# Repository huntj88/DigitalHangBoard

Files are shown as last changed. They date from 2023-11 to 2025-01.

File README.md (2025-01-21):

# Digital Hangboard
#### Project Album and YouTube demo
* https://photos.app.goo.gl/wRxz9BxxeJGzHZhK6
* https://youtube.com/shorts/t4RoINdm0Y4

---

assembled hangboard
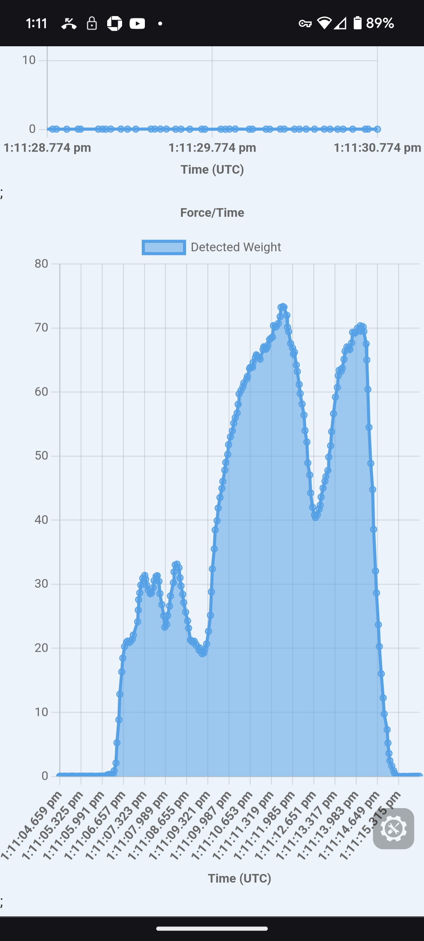
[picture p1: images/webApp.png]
web app


I thought it would be fun to create a Hangboard capable of measuring and logging how much weight I could apply through my fingertips. A hangboard is a tool that is commonly used by rock climbers, but usually they don't have integrated electronics.

Over the course of this project I was able to enjoy playing with (to varying degrees) 3d modeling, 3d printing, cnc routing, react + next.js, bluetooth, electrical engineering, firmware development.

I used an esp32 microcontroller to read the sensors and report the data to a tiny screen, as well as a web app over bluetooth.

To detect the weight I used 4 load cells and 4 high resolution analog to digital converters.
* https://www.adafruit.com/product/4538
* https://www.robotshop.com//products/micro-load-cell-50-kg

When I started this project I did not have access to a CNC router, but I did have a 3d printer. I designed the model so that it could be manufactured on either, which made it easy to iterate and validate my design with the tools at my disposal.

comparing 3d printed vs cnc routered parts
cnc router during routing operation

To make this work I designed the hangboard as a series of layers that was held together by Stainless Steel threaded rods, lock nuts, and washers.

* M5 x 150mm Fully Threaded Rod 304 Stainless Steel - 6 pieces
* M5 x 0.8mm Nylon Insert Hex Lock Nuts 304 Stainless Steel
* M5 x 15mm x 1.2mm Large Flat Washers, 304 Stainless Steel

---

The Mounting system is pretty cool. I though a lot about different ways to mount it, but I had a few constraints I wanted to work within.
* Limit manual work steps
* No new materials, just wood ideally
* Not bulky, ideally hidden

There are two rectangular slots in the front and back of the hangboard. A regtangular peg that fits in the back slot is attached to a wall. Once the peg is in place, the handboard slot should fit over it. This keeps it from moving Left, Right, Up, and Down.

After the hangboard is in place, another identical peg is placed in the slot in the front, and screws are driven all the way into the same backing material as the first peg. This prevents the hangboard from sliding forward off the first peg, and gives it additional support.

This means the Hangboard is held to the backing material by 12 heavy duty screws.

back mount peg hole
front mount

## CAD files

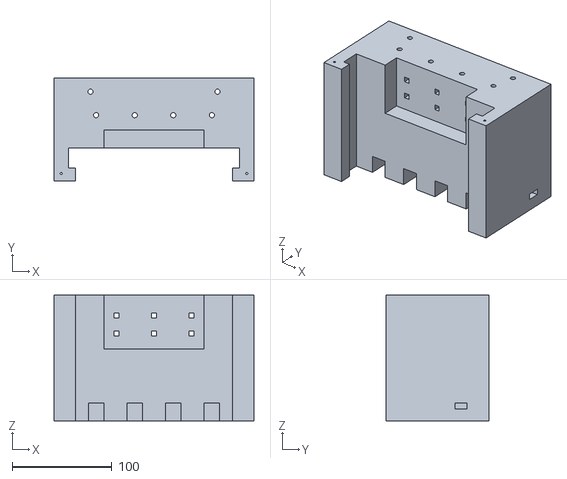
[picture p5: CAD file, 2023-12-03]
cad/v2/dhb-fullModel.stl
200.0 x 102.6 x 126.0

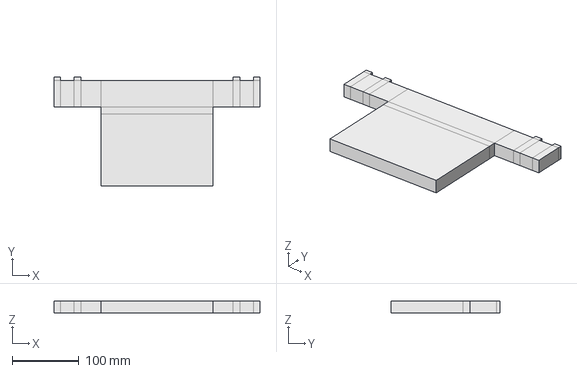
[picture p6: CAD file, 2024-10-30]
cad/v2/digitalHangBoardV2.FCStd
308.0 x 163.0 x 18.0 mm

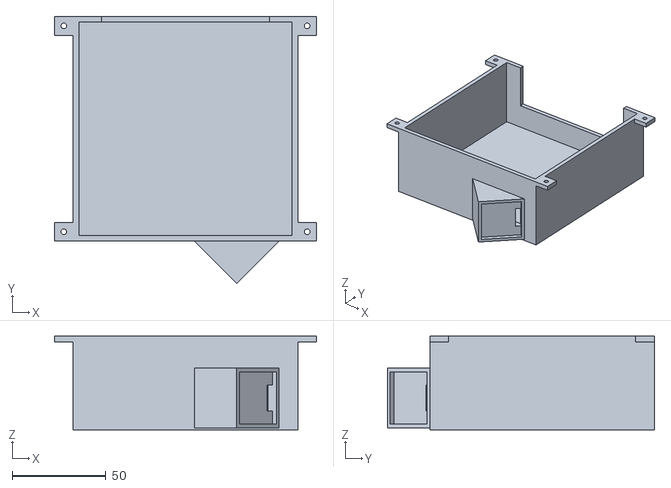
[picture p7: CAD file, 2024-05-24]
cad/v2/dhb-electronicsCover.stl
140.0 x 142.6 x 50.0

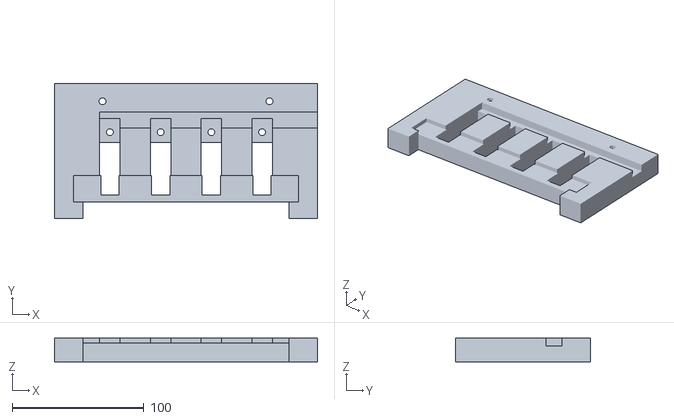
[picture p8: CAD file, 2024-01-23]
cad/v2/dhb-Layer0.stl
200.0 x 102.6 x 18.0

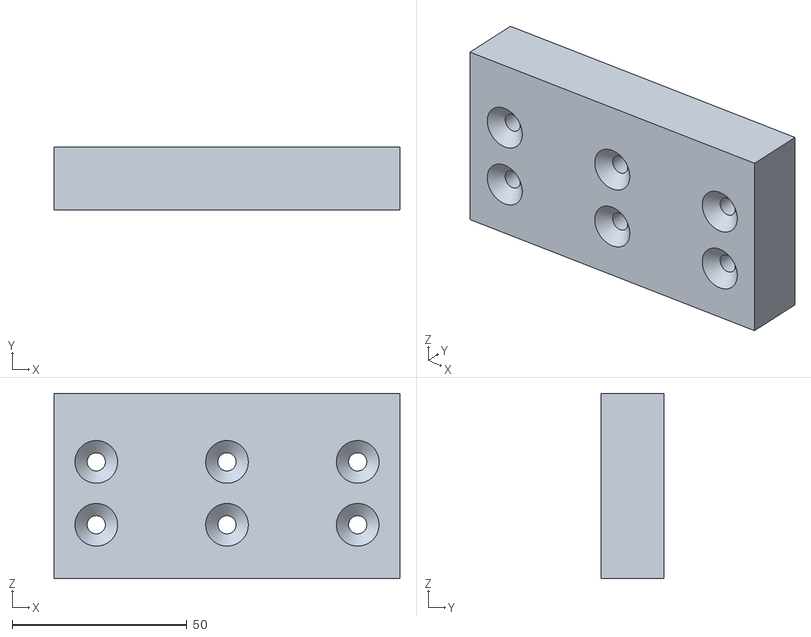
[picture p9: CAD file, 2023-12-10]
cad/v2/dhb-supportOrClamp.stl
99.0 x 18.0 x 53.0

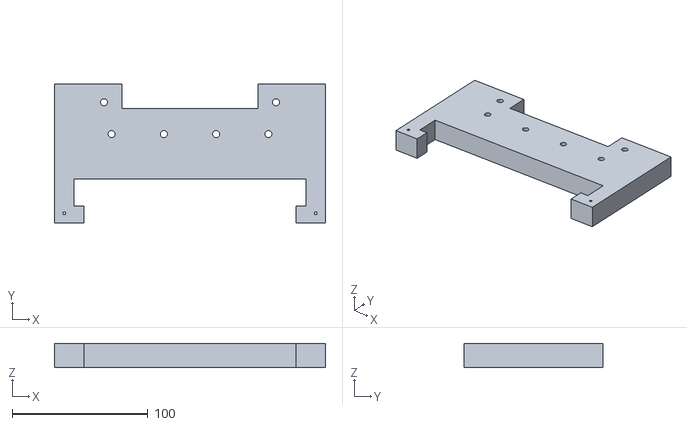
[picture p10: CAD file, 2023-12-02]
cad/v2/dhb-Layer1-3.stl
200.0 x 102.6 x 18.0

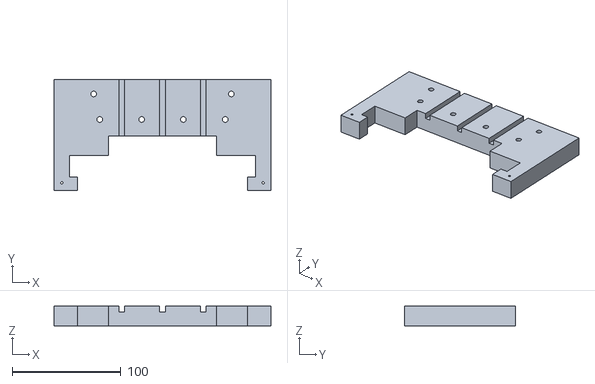
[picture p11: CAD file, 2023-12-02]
cad/v2/dhb-Layer4-5.stl
200.0 x 102.6 x 18.0

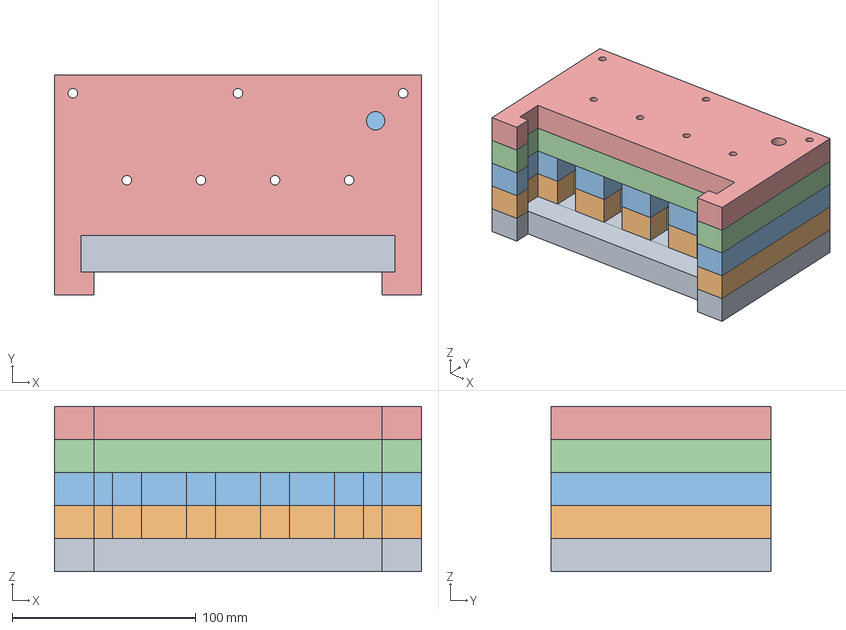
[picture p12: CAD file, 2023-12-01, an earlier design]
cad/v1/digitalHangBoard.FCStd
200.0 x 120.0 x 90.0 mm
BooleanFragments.62
BooleanFragments.63
BooleanFragments.64
BooleanFragments.65
BooleanFragments.66

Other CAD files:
cad/v2/dhb-Layer6.stl

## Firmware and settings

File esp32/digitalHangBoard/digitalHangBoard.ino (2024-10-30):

#include <Preferences.h>

Preferences calibration;

// error code format
// code:index

// error code meanings
// 0 uncalibrated TODO
// 1 scale read error
float attemptMax = 0;
float lastAttemptMax = 0;
String calibrationErrors = "";

void setup() {
  Serial.begin(115200);
  calibration.begin("dhb-calibration", false);
  // calibration.clear();
  // calibration.putFloat("scale" + 0, 0.0000485);
  // calibration.putFloat("scale" + 1, 0.0000505);
  // calibration.putFloat("scale" + 2, 0.0000492);
  // calibration.putFloat("scale" + 3, 0.00005);

  setupScreen();

  std::function<float(const int)> getCalibration = [calibration](int index) {
    return calibration.getFloat("scale" + index, -1);
  };
  std::function<void(const int, const float)> setCalibration = [calibration](int index, float m) {
    calibration.putFloat("scale" + index, m);
  };

  displayTitleSubtitle("Starting BlueTooth", getBLEServerName());
  delay(1000);
  setupBluetoothServer(getCalibration, setCalibration);

  displayTitleSubtitle("Calibrating", "Don't touch Hangboard");
  delay(1000);
  setupScales();

  checkForCalibrationErrors();
}

void loop() {
  if (calibrationErrors.length() > 0) {
    Serial.println(calibrationErrors);
    displayErrors(calibrationErrors);
    delay(5000);

    // TODO: add calibration characteristics to bluetooth
    // check again in case calibration has been set over bluetooth
    checkForCalibrationErrors();
    return;
  }

  int rawValues[] = { -2147483648, -2147483648, -2147483648, -2147483648 };
  String errors = "";

  for (int index = 0; index < 4; index++) {
    int valueForIndex = readScale(index);
    rawValues[index] = valueForIndex;

    if (valueForIndex == -2147483648) {
      errors += "1:";
      errors += index;
      errors += "\n";
    }
  }

  if (isBluetoothClientConnected()) {
    for (int index = 0; index < 4; index++) {
      int valueForIndex = rawValues[index];
      if (valueForIndex != -2147483648) {
        sendWeightValue(index, valueForIndex);
      }
    }
  }

  if (errors.length() == 0) {
    float sumWeight = 0;
    for (int index = 0; index < 4; index++) {
      int valueForIndex = rawValues[index];
      sumWeight += calculateWeightFromValue(index, valueForIndex);
    }

    float calibratedSum = calibrateSumWeight(sumWeight);


    float maxWeight = trackAndGetMaxWeight(calibratedSum);
    displayWeight(calibratedSum, maxWeight);
  } else {
    Serial.println(errors);
    displayErrors(errors);
  }

  delay(10);
}

float calculateWeightFromValue(int index, int value) {
  // y = mx + b, b is always 0
  float m = calibration.getFloat("scale" + index, -1);
  float y = m * value;
  return y;
}

void checkForCalibrationErrors() {
  calibrationErrors = "";
  for (int index = 0; index < 4; index++) {
    Serial.print("scale");
    Serial.print(index);
    Serial.print(" calibration: ");
    float calibrationValue = calibration.getFloat("scale" + index, -1);
    Serial.println(calibrationValue, 7);

    if (calibrationValue == -1) {
      calibrationErrors += "0:";
      calibrationErrors += index;
      calibrationErrors += "\n";
    }
  }
}

float trackAndGetMaxWeight(float sumWeight) {
  if (sumWeight > attemptMax && sumWeight > 2) {
    attemptMax = sumWeight;
  } else if (sumWeight < 2 && attemptMax != 0) {
    lastAttemptMax = attemptMax;
    attemptMax = 0;
  }

  if (attemptMax != 0) {
    return attemptMax;
  } else {
    return lastAttemptMax;
  }
}

float calibrateSumWeight(float sumWeight) {
  float scaleFactor = 1.1071; // found with weight applied through handboard hold
  return scaleFactor * sumWeight;
}

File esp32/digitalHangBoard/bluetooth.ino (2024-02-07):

#include <BLEDevice.h>
#include <BLEServer.h>
#include <BLEUtils.h>
#include <BLE2902.h>
#include <functional>

#define bleServerName "Digital Hangboard"
#define SERVICE_UUID "4e035799-bfff-47dd-a531-4ada55e703ec"

/* Check if Bluetooth configurations are enabled in the SDK */
#if !defined(CONFIG_BT_ENABLED) || !defined(CONFIG_BLUEDROID_ENABLED)
#error Bluetooth is not enabled! Please run `make menuconfig` to and enable it
#endif

// TODO: use prototype definitions, like in scales.ino, to make this less repetetive

BLECharacteristic scale0Characteristic("6766fbea-844a-459a-8def-643852f016b8", BLECharacteristic::PROPERTY_NOTIFY);
BLE2902 scale0CCC;

BLECharacteristic scale1Characteristic("3f19be02-a46f-4ea7-851b-1c2b891cf63e", BLECharacteristic::PROPERTY_NOTIFY);
BLE2902 scale1CCC;

BLECharacteristic scale2Characteristic("d064d929-1cf3-42df-abe9-b5e8a9e0e2bd", BLECharacteristic::PROPERTY_NOTIFY);
BLE2902 scale2CCC;

BLECharacteristic scale3Characteristic("15c40fb5-0311-465a-a77c-c42a8282e7cf", BLECharacteristic::PROPERTY_NOTIFY);
BLE2902 scale3CCC;

BLECharacteristic scaleCalibrationCharacteristic("04722e1f-2029-4588-ae7d-8c764a0163af", BLECharacteristic::PROPERTY_READ | BLECharacteristic::PROPERTY_WRITE);

BLEServer *pServer;

class BLEConnectionCallbacks : public BLEServerCallbacks {
  // server stops advertising on connected
  void onConnect(BLEServer *pServer) {
    Serial.println("connected");
    pServer->startAdvertising();
  };
  void onDisconnect(BLEServer *pServer) {
    Serial.println("disconnected");
    pServer->startAdvertising();
  }
};

// class CalibrationWriteCallback : public BLECharacteristicCallbacks {
//   void onWrite(BLECharacteristic *pCharacteristic) {
//     // String id = pCharacteristic->getUUID().toString();
//     // TODO: write to storage if set from remote client

//     // String value = pCharacteristic->getValue();

//     // if (value.length() > 0) {
//     //   Serial.println("*********");
//     //   Serial.print("New value: ");
//     //   for (int i = 0; i < value.length(); i++)
//     //     Serial.print(value[i]);

//     //   Serial.println();
//     //   Serial.println("*********");
//     // }
//   }
// };

void setupTestingMacAddress() {
  // appears as a new device, so cache on client doesn't matter
  uint8_t base_mac_addr[8] = { 0x01, 0x08, 0x07, 0x07, 0x05, 0x06 };
  base_mac_addr[0] &= ~0x01;  // make unicast
  base_mac_addr[0] |= 0x02;   // mark as locally administered
  Serial.println(esp_base_mac_addr_set(base_mac_addr));
}

void setupBluetoothServer(std::function<float(const int)> getCalibration, std::function<void(const int, const float)> setCalibration) {
  setupTestingMacAddress();
  BLEDevice::init(bleServerName);

  pServer = BLEDevice::createServer();
  pServer->setCallbacks(new BLEConnectionCallbacks());

  BLEService *dhbService = pServer->createService(SERVICE_UUID);

  scale0CCC.setNotifications(true);
  scale0Characteristic.addDescriptor(&scale0CCC);
  dhbService->addCharacteristic(&scale0Characteristic);

  scale1CCC.setNotifications(true);
  scale1Characteristic.addDescriptor(&scale1CCC);
  dhbService->addCharacteristic(&scale1Characteristic);

  scale2CCC.setNotifications(true);
  scale2Characteristic.addDescriptor(&scale2CCC);
  dhbService->addCharacteristic(&scale2Characteristic);

  scale3CCC.setNotifications(true);
  scale3Characteristic.addDescriptor(&scale3CCC);
  dhbService->addCharacteristic(&scale3Characteristic);

  float calibration0 = getCalibration(0);
  float calibration1 = getCalibration(1);
  float calibration2 = getCalibration(2);
  float calibration3 = getCalibration(3);
  std::string calibration = ftos(calibration0) + "," + ftos(calibration1) + "," + ftos(calibration2) + "," + ftos(calibration3);
  scaleCalibrationCharacteristic.setValue(calibration);
  // scaleCalibrationCharacteristic.setCallbacks(new CalibrationWriteCallback());
  dhbService->addCharacteristic(&scaleCalibrationCharacteristic);


  dhbService->start();
  BLEAdvertising *pAdvertising = BLEDevice::getAdvertising();
  pAdvertising->addServiceUUID(SERVICE_UUID);
  pServer->getAdvertising()->start();
  Serial.println("Bluetooth Started! Ready to pair...");
}

bool isBluetoothClientConnected() {
  return pServer->getConnectedCount() > 0;
}

String getBLEServerName() {
  return bleServerName;
}

void sendWeightValue(int index, int value) {
  if (index == 0) {
    scale0Characteristic.setValue(value);
    scale0Characteristic.notify();
  } else if (index == 1) {
    scale1Characteristic.setValue(value);
    scale1Characteristic.notify();
  } else if (index == 2) {
    scale2Characteristic.setValue(value);
    scale2Characteristic.notify();
  } else if (index == 3) {
    scale3Characteristic.setValue(value);
    scale3Characteristic.notify();
  }
}

// float to string with precision of 7
std::string ftos(float f) {
  return std::string(String(f, 7).c_str());
}

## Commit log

2023-11-11 digital hangboard initial cad
    [digitalHangBoard.FCStd]
2023-11-11 added template project for web
    [digitalHangBoard.FCStd]
2023-11-12 fixed size to fit load cell, added android app that loads web app in web view
    [digitalHangBoard.FCStd]
2023-11-12 improved design of 3d model
    [digitalHangBoard.FCStd]
2023-11-13 cleaned up model, added esp32 program that collects sensor data from a load cell and sends the value to bluetooth connected device
    [digitalHangBoard.FCStd]
2023-11-14 added port for usb cable
    [digitalHangBoard.FCStd]
2023-11-14 send weight sensor values over bluetooth in json format
2023-11-22 web bluetooth connection to esp32
2023-11-24 added rxjs and made rxjs wrapper around bluetooth sensor data
2023-11-25 disabled y axis animation
2023-11-29 now using four nau7802 ic's to measure scales, using an i2c multiplexer
2023-12-01 increased data resolution, improved animation on live graph, working on changes to cad design v2
    [digitalHangBoard.FCStd, digitalHangBoardV2.FCStd]
2023-12-01 progress on v2 cad
    [digitalHangBoardV2.FCStd]
2023-12-01 added m2 bolt holes at front of model
    [digitalHangBoardV2.FCStd]
2023-12-01 added channel for load cell wires
    [digitalHangBoardV2.FCStd]
2023-12-02 added pockets for clamp screws
    [digitalHangBoardV2.FCStd]
2023-12-02 made support block
    [digitalHangBoardV2.FCStd]
2023-12-02 split into layers for cnc
    [digitalHangBoardV2.FCStd]
2023-12-02 cleanup, exported stl's
    [dhb-Layer0.stl, dhb-Layer1-3.stl, dhb-Layer4-5.stl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]
2023-12-02 changed to round holes for support/clamp
    [digitalHangBoardV2.FCStd]
2023-12-02 made model of hold mount
    [digitalHangBoardV2.FCStd]
2023-12-02 added margin for support piece
    [digitalHangBoardV2.FCStd]
2023-12-03 made wire channel deeper and wider
    [digitalHangBoardV2.FCStd]
2023-12-03 slightly wider wire channel
    [dhb-Layer0.stl, digitalHangBoardV2.FCStd]
2023-12-03 updated full model
    [dhb-fullModel.stl]
2023-12-05 made support screw head sit deeper
    [dhb-supportOrClamp.stl, digitalHangBoardV2.FCStd]
2023-12-05 corrected width of support from 17mm to 18mm
    [dhb-supportOrClamp.stl, digitalHangBoardV2.FCStd]
2023-12-10 adjusted screw head size on support
    [dhb-supportOrClamp.stl, digitalHangBoardV2.FCStd]
2023-12-10 linear regression calibration basics
2024-01-20 new bottom layer
    [dhb-Layer0.stl, digitalHangBoardV2.FCStd]
2024-01-20 made bottom layer be open where load cell bends
    [digitalHangBoardV2.FCStd]
2024-01-21 reordering of objects to make it easier to edit bottom layer part
    [digitalHangBoardV2.FCStd]
2024-01-23 updated bottom layer stl
    [dhb-Layer0.stl]
2024-02-03 better handling of calibration errors, initialization logs on screen, increased font size for weight value
    [bluetooth.ino, digitalHangBoard.ino, screen.ino]
2024-02-07 get calibration values from hangboard over bluetooth
2024-02-10 moment includes values from all scales, added janky but good enough for now bulk insert
2024-02-11 hide save button on connected page SessionGraph
2024-02-13 added max weight to led screen
2024-03-21 created job to cut layer 0 on cnc router
    [digitalHangBoardV2.FCStd]
2024-03-23 layer 1-3 cnc job
    [digitalHangBoardV2.FCStd]
2024-03-23 layer 4-5 cnc job
    [digitalHangBoardV2.FCStd]
2024-03-23 layer 6 cnc job
    [digitalHangBoardV2.FCStd]
2024-03-24 support cnc job
    [digitalHangBoardV2.FCStd]
2024-03-24 adjusting support cnc job
    [digitalHangBoardV2.FCStd]
2024-03-24 adjusting support cnc job, decreased time
    [digitalHangBoardV2.FCStd]
2024-04-25 Fixed error with inserting decimals into integer column.
    also calibration
    [digitalHangBoard.ino]
2024-05-24 very simple electronics housing for hangboard
    [dhb-electronicsCover.stl, digitalHangBoardV2.FCStd]
2024-05-24 better bulk insert oh time series data
2024-10-26 calibration hold cad model
    [digitalHangBoardV2.FCStd]
2024-10-30 made hold mount for calibration purposes
    [digitalHangBoardV2.FCStd]
2024-10-30 added calibration value from measuring with weight applied through handboard instead of sensors directly
